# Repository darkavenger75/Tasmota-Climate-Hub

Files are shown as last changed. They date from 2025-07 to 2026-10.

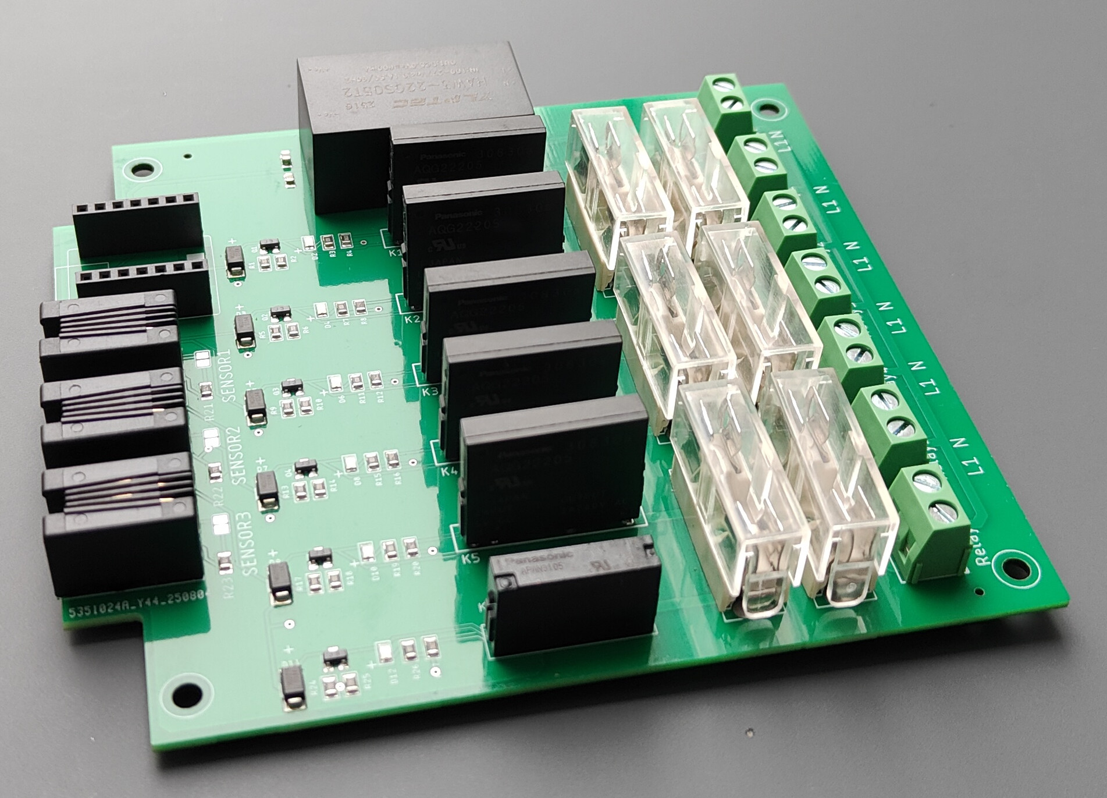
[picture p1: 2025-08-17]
NoZigbee/TasmotaTerra_PCB.jpg

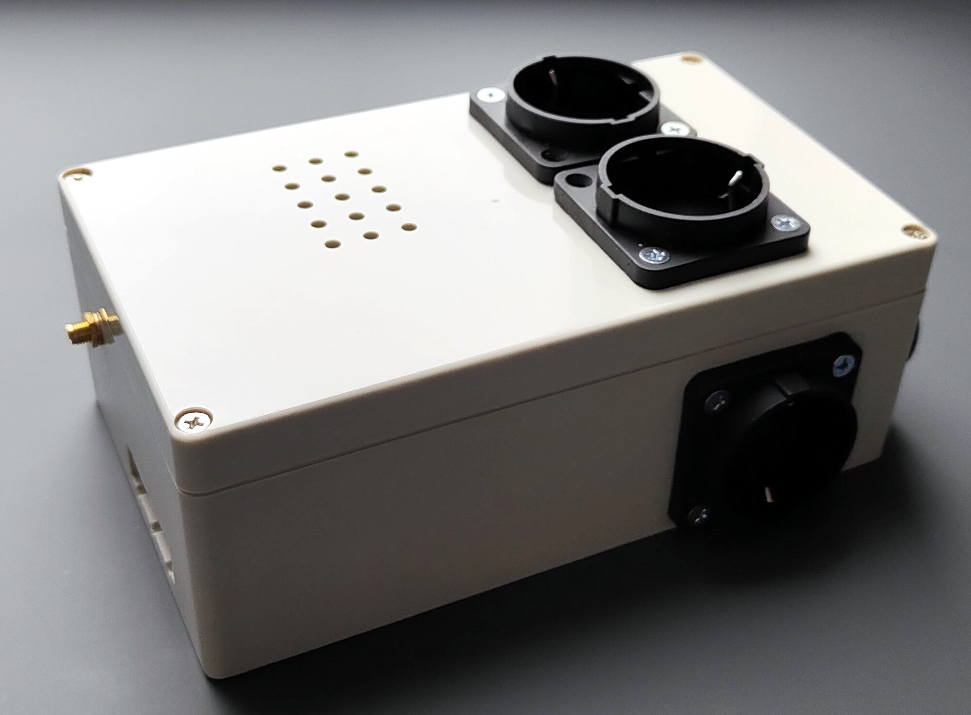
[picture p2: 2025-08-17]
NoZigbee/TasmotaTerra_Case.jpg

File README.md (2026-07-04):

Seeed Xiao ESP32-C6 based climate controller for Tasmota

A flexible Tasmota hub with 4 sensor inputs and 5 relay outputs. Can replace your collection of timer switches and thermostats (e.g. fish tank, terrarium) to allow for more complex control and the ability to check/change settings via the web interface. This is a stand-alone device not requiring internet access or any external controller/hub. Being based on Tasmota it can be integrated into e.g. Home Assistant. 
- RJ9 inputs for Sonoff WTS01 or THS01 (or whatever you want to connect requiring 1 GPIO, GND, 3.3V).
- Solid state relay main voltage outputs, max. 2A each.
- Option to add Zigbee module Ebyte E18-MS1 to integrate some of your Zigbee devices (check https://zigbee.blakadder.com/zigbee2tasmota.html for compatibility).

Instructions
- Eagle schematic, board, Gerber, BOM and CPL files are provided. Someone like JLCPCB can make the PCB and assemble it for you (check placement of components!). You might have to preorder the RJ9 sockets and solid state relays (Omron or Panasonic) or add them later yourself.
- The unit has an integrated power supply. There is mains voltage on the board, do not fry yourself!
- Flash with Tasmota for ESP32C6. If you want Zigbee support you must compile your own version, e.g. with Gitpod.
- Set-up GPIO according to "Tasmota_ESP32C6_GPIO_Config.png" and your own configuration.
- If attaching DS18x20 close the jumpers on the respective ports to add pullup resistors.
- If attaching THS01 (SI7021) add rule "ON System#Init DO DhtDelay 480,40 ENDON" or sensor might not work reliably.
- If you want the Zigbee module you have to flash it first with Z-Stack Home 1.2 coordinator firmware from https://github.com/Koenkk/Z-Stack-firmware. A debug port is provided. See https://tasmota.github.io/docs/CC2530/#flash-zigbee-adapter for options. Do not forget to close the jumper next to the board such that it will be powered.
- An example rule with 6 timers (3x ON/OFF) set to "rule" is provided. It will switch relays 1 and 2 on and off according to timers 1/2 and 3/4. It will switch relay 3 according to the temperture input from DS18B20 with limits chosen by timer 3 from mem1/mem2 (timer on) or mem3/mem4 (timer off). Unlike using the timers directly to switch the relays this rule sets the outputs correctly after restarting the device.
- I recommend to use the autoexec.be in the Berry folder instead of using rules.

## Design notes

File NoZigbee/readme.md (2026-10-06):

A different version of the Tasmota hub without Zigbee, with only 3 inputs but 6 relays, including a conventional 5A one (on GPIO23).
Can be squeezed into a Tru Components F1 TC-6649500 case together with 5 - 6 AS 45081 power sockets and a C-14 mains connector.
Or use a smaller 3D printed shell (3DShell_Tasmota_ESP32C6-6c.zip) together with Wieland GST18 i3 connectors.

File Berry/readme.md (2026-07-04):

Berry and HASPmota code to control your terrarium and show relevant data on an ESP32-4848S040 display (e.g. from https://de.aliexpress.com/item/1005007606761287.html?gatewayAdapt=glo2deu4itemAdapt). 
1) Configure the ESP32C6 climate hub as described on the main project page, including GPIO configuration.
3) Copy "autoexec.be" to the device. No other "rules" required but timers 1 (begin) and 2 (end) determine what is daytime.
4) Copy uPlot's uPlot.iife.min.js and uPlot.min.css files to the file system. This allows for creating the temperature chart without internet access.
5) Adjust timers and temperatures as desired. As a minimum timer1 and timer2 are required: day starts at timer1, ends at timer2.  
6) Install the "tasmota32s3-qio_opi" version of Tasmota on the ESP32-4848S040.
7) Use "auto-conf" and select "S3-4848S040"
8) Copy "autoexec_remote.be" - rename to "autoexec.be" - and the .jsonl file to the device.
9) Change the URL in autoexec.be to match your climate hub (currently set to http://tasmota-terra/).
10) Restart and enjoy.

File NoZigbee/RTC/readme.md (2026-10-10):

Another version:
- RTC onboard so rules depending on time will not stop working if wifi connection is lost
- Opto-isolator + TRIAC instead of SSR: cheaper given the current price of AQG2****
- Long and flat shell with Wieland connectors. Much more elegant than the Tru Components F1 TC-6649500 case

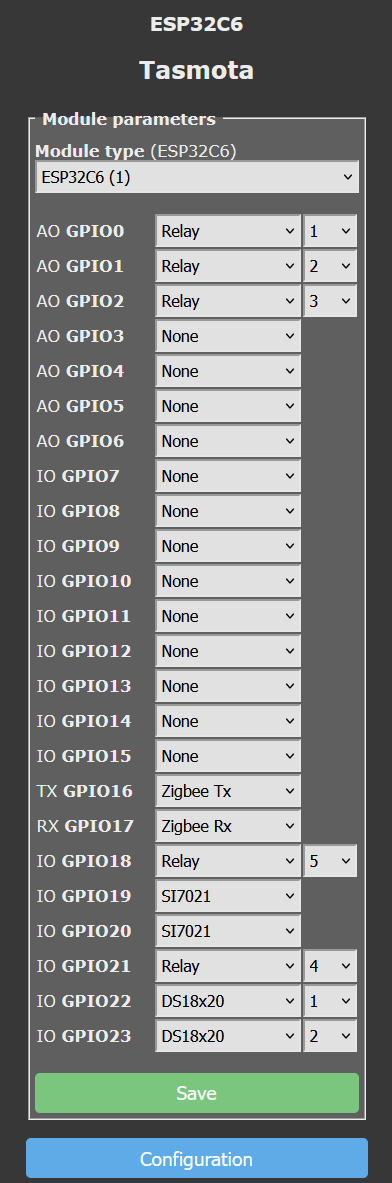
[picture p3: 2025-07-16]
Tasmota_ESP32C6_GPIO_Config.png

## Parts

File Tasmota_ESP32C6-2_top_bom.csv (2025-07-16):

Comment | Designator | Footprint | LCSC Part #
0.01uF(1KV) | C1 C2 C3 C4 C5 | C1206 | C77098
1K | R3 R7 R11 R15 R19 | R0805 | C17513
1x4P | DEBUG | 1X05 | C492404
1x7P | U$1 | XIAO_ESP32C6 | C2832270
1x7P | U$1a | XIAO_ESP32C6 | C2832270
2k | R1 R5 R9 R13 R17 | R0805 | C17604
4k7 | R21 R22 R23 R24 | R0805 | C17673
10K | R2 R6 R10 R14 R18 | R0805 | C17414
22 | R4 R8 R12 R16 R20 | R0805 | C17561
22uF | C6 | C0805 | C45783
100nF | C7 | C0805 | C49678
DB127V-5.08-2P-GN-S | X1 X2 X3 X4 X5 X6 | W237-102
FH1-206Z | F1 F2 F3 F4 F5 | FUSEHOLDER_10
GMX-N-44 | SENSOR1 SENSOR2 SENSOR3 SENSOR4 | GMX-N-4
HAW3-220S05T2 | U$3 | HAW3-220S05T2
KT-0805G | D2 D4 D6 D8 D10 | LED-0805 | C2297
S9013 | Q1 Q2 Q3 Q4 Q5 | SOT23 | C6749
SS34 | D1 D3 D5 D7 D9 | DO-214AC | C8678

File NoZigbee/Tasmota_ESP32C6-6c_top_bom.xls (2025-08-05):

Comment | Designator | Footprint | JLCPCB Part #
1K | R3,R7,R11,R15,R19,R26 | R0805 | C17513
4k7 | R21,R22,R23 | R0805 | C17673
S9013 | Q1,Q2,Q3,Q4,Q5,Q6 | SOT23 | C20069127
22uF | C6 | C0805 | C45783
2k | R1,R5,R9,R13,R17,R24 | R0805 | C17604
100nF | C7 | C0805 | C49678
APAN3105 | K6 | RELAY_APAN3105 | C90227
PTF-15 | F6,F4,F2,F5,F3,F1 | SH225 | C842712
22 | R4,R8,R12,R16,R20,R27 | R0805 | C17561
AQG22205 | K1,K2,K3,K4,K5 | AQG | C124000
GMX-N-44 | SENSOR1,SENSOR2,SENSOR3 | GMX-N-4 | C6049369
SS34 | D1,D3,D5,D7,D9,D11 | DO-214AC | C8678
1x7P | U$1,U$1B | XIAO_ESP32C6 | C2832270
10K | R2,R6,R10,R14,R18,R25 | R0805 | C17414
KT-0805G | D2,D4,D6,D8,D10,D12 | LED-0805 | C2297
DB127V-5.08-2P-GN-S | X1,X2,X3,X4,X5,X6,X7 | W237-102 | C3018698
HAW3-220S05T2 | U$3 | HAW3-220S05T2 | C19724491

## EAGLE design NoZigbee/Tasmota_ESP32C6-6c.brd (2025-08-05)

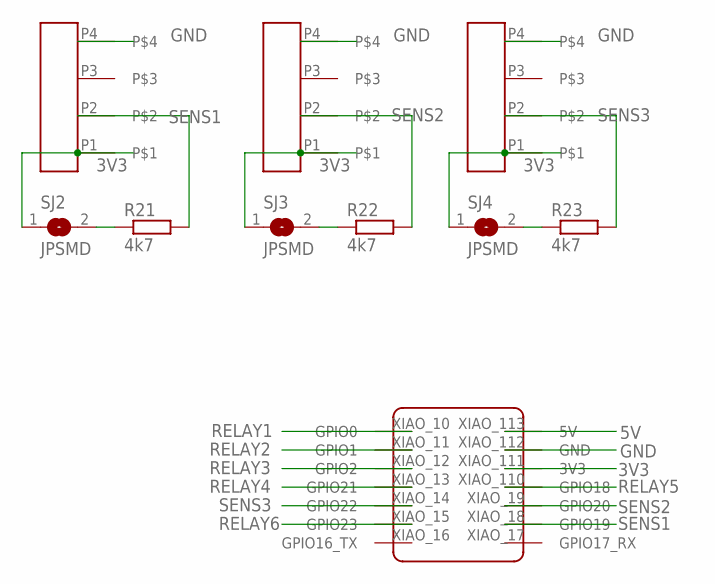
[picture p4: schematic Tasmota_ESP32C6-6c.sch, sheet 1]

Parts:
R21, R22, R23: 4k7; R0805
SENSOR1, SENSOR2, SENSOR3: GMX-N-44; GMX-N-4
SJ2, SJ3, SJ4: JPSMD; SJ
U$1: 1x7P; XIAO_ESP32C6

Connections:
3V3: SENSOR1.P1, SENSOR2.P1, SENSOR3.P1, SJ2.1, SJ3.1, SJ4.1, U$1.XIAO_111 (3V3)
5V: U$1.XIAO_113 (5V); also elsewhere on the board
GND: SENSOR1.P4, SENSOR2.P4, SENSOR3.P4, U$1.XIAO_112 (GND); also elsewhere on the board
unnamed: R21.1, SJ2.2
unnamed: R22.1, SJ3.2
unnamed: R23.1, SJ4.2
RELAY1: U$1.XIAO_10 (GPIO0); also elsewhere on the board
RELAY2: U$1.XIAO_11 (GPIO1); also elsewhere on the board
RELAY3: U$1.XIAO_12 (GPIO2); also elsewhere on the board
RELAY4: U$1.XIAO_13 (GPIO21); also elsewhere on the board
RELAY5: U$1.XIAO_110 (GPIO18); also elsewhere on the board
RELAY6: U$1.XIAO_15 (GPIO23); also elsewhere on the board
SENS1: R21.2, SENSOR1.P2, U$1.XIAO_18 (GPIO19)
SENS2: R22.2, SENSOR2.P2, U$1.XIAO_19 (GPIO20)
SENS3: R23.2, SENSOR3.P2, U$1.XIAO_14 (GPIO22)

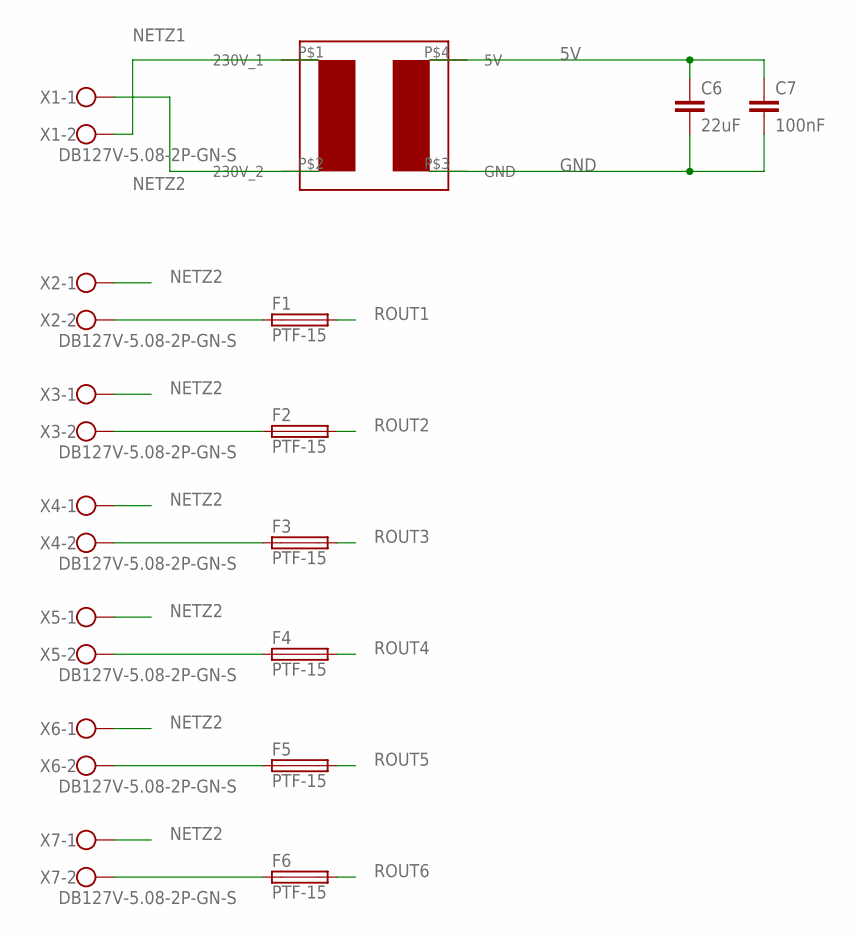
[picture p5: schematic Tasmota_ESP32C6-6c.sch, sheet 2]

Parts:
C6: 22uF; C0805
C7: 100nF; C0805
F1, F2, F3, F4, F5, F6: PTF-15; SH22,5
U$3: HAW3-220S05T2
X1, X2, X3, X4, X5, X6, X7: DB127V-5.08-2P-GN-S; W237-102

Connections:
5V: C6.1, C7.1, U$3.P$4 (5V); also elsewhere on the board
GND: C6.2, C7.2, U$3.P$3 (GND); also elsewhere on the board
unnamed: F1.1, X2.2
unnamed: F2.1, X3.2
unnamed: F3.1, X4.2
unnamed: F4.1, X5.2
unnamed: F5.1, X6.2
unnamed: F6.1, X7.2
NETZ1: U$3.P$1 (230V_1), X1.2; also elsewhere on the board
NETZ2: U$3.P$2 (230V_2), X1.1, X2.1, X3.1, X4.1, X5.1, X6.1, X7.1
ROUT1: F1.2; also elsewhere on the board
ROUT2: F2.2; also elsewhere on the board
ROUT3: F3.2; also elsewhere on the board
ROUT4: F4.2; also elsewhere on the board
ROUT5: F5.2; also elsewhere on the board
ROUT6: F6.2; also elsewhere on the board

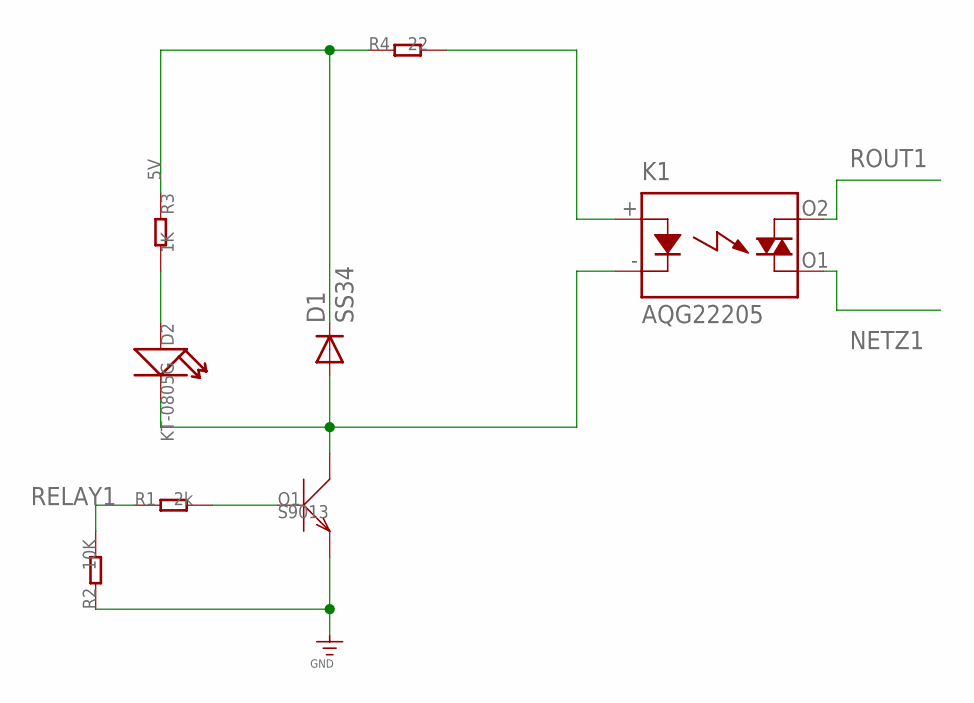
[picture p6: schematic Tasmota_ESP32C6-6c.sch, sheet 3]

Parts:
D1: SS34; DO-214AC
D2: KT-0805G; LED-0805
K1: AQG22205; AQG
Q1: S9013; SOT23
R1: 2k; R0805
R2: 10K; R0805
R3: 1K; R0805
R4: 22; R0805

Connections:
5V: D1.C, R3.1, R4.1; also elsewhere on the board
GND: Q1.2 (E), R2.1; also elsewhere on the board
unnamed: Q1.1 (B), R1.2
unnamed: D1.A, D2.-, K1.- (K), Q1.3 (C)
unnamed: D2.+, R3.2
unnamed: K1.+ (A), R4.2
NETZ1: K1.O1 (DS2); also elsewhere on the board
RELAY1: R1.1, R2.2; also elsewhere on the board
ROUT1: K1.O2 (DS1); also elsewhere on the board

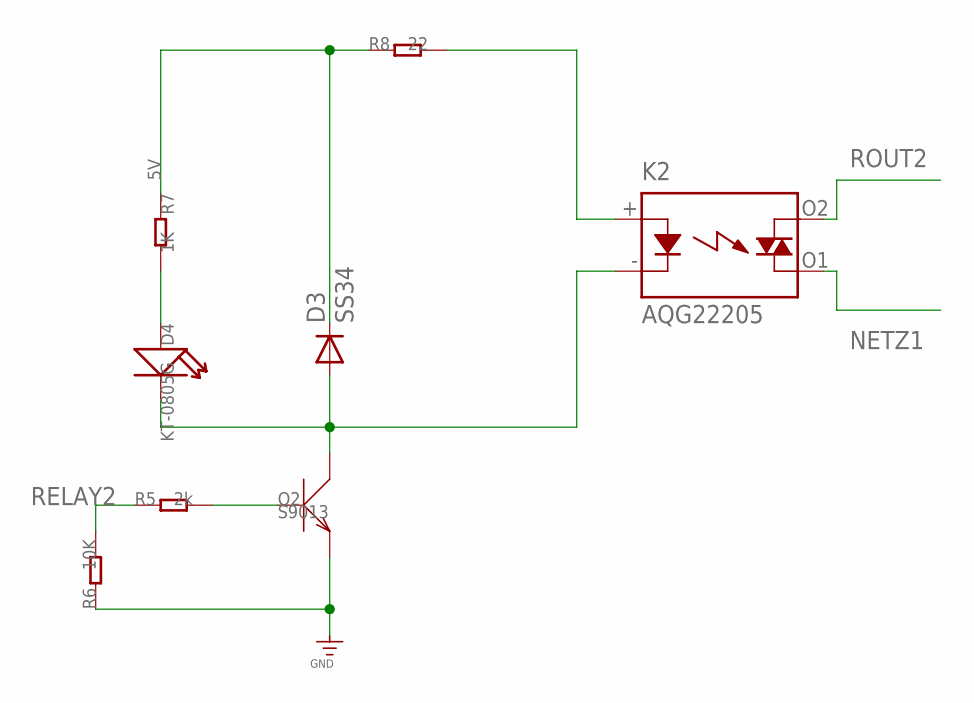
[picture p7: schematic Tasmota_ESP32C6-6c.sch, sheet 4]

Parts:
D3: SS34; DO-214AC
D4: KT-0805G; LED-0805
K2: AQG22205; AQG
Q2: S9013; SOT23
R5: 2k; R0805
R6: 10K; R0805
R7: 1K; R0805
R8: 22; R0805

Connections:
5V: D3.C, R7.1, R8.1; also elsewhere on the board
GND: Q2.2 (E), R6.1; also elsewhere on the board
unnamed: Q2.1 (B), R5.2
unnamed: D3.A, D4.-, K2.- (K), Q2.3 (C)
unnamed: D4.+, R7.2
unnamed: K2.+ (A), R8.2
NETZ1: K2.O1 (DS2); also elsewhere on the board
RELAY2: R5.1, R6.2; also elsewhere on the board
ROUT2: K2.O2 (DS1); also elsewhere on the board

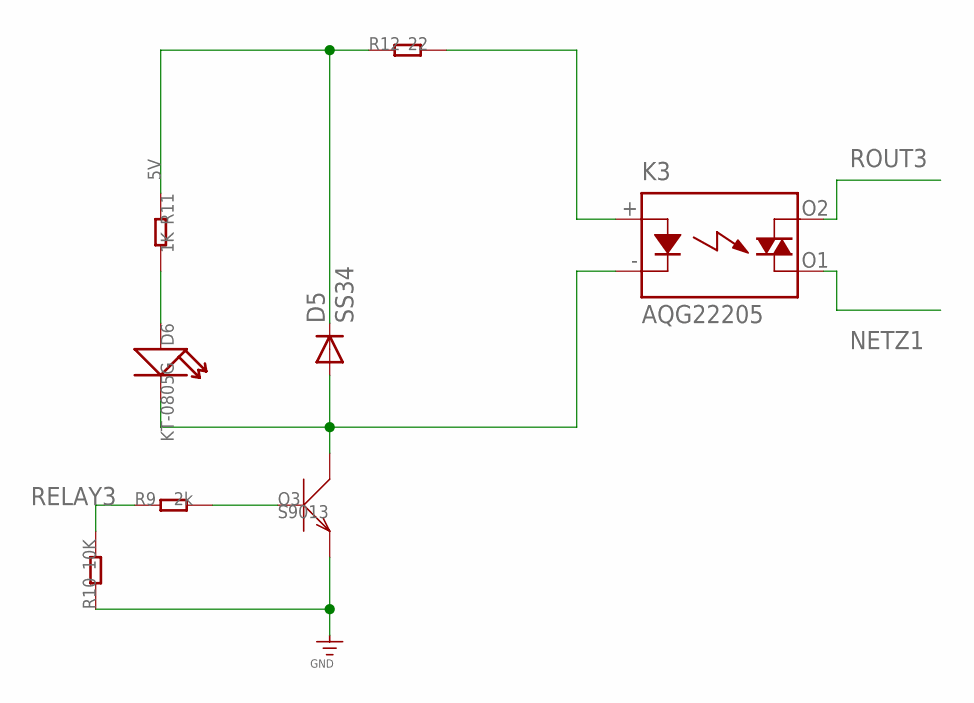
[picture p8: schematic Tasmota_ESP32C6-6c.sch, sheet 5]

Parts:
D5: SS34; DO-214AC
D6: KT-0805G; LED-0805
K3: AQG22205; AQG
Q3: S9013; SOT23
R9: 2k; R0805
R10: 10K; R0805
R11: 1K; R0805
R12: 22; R0805

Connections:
5V: D5.C, R11.1, R12.1; also elsewhere on the board
GND: Q3.2 (E), R10.1; also elsewhere on the board
unnamed: Q3.1 (B), R9.2
unnamed: D5.A, D6.-, K3.- (K), Q3.3 (C)
unnamed: D6.+, R11.2
unnamed: K3.+ (A), R12.2
NETZ1: K3.O1 (DS2); also elsewhere on the board
RELAY3: R9.1, R10.2; also elsewhere on the board
ROUT3: K3.O2 (DS1); also elsewhere on the board

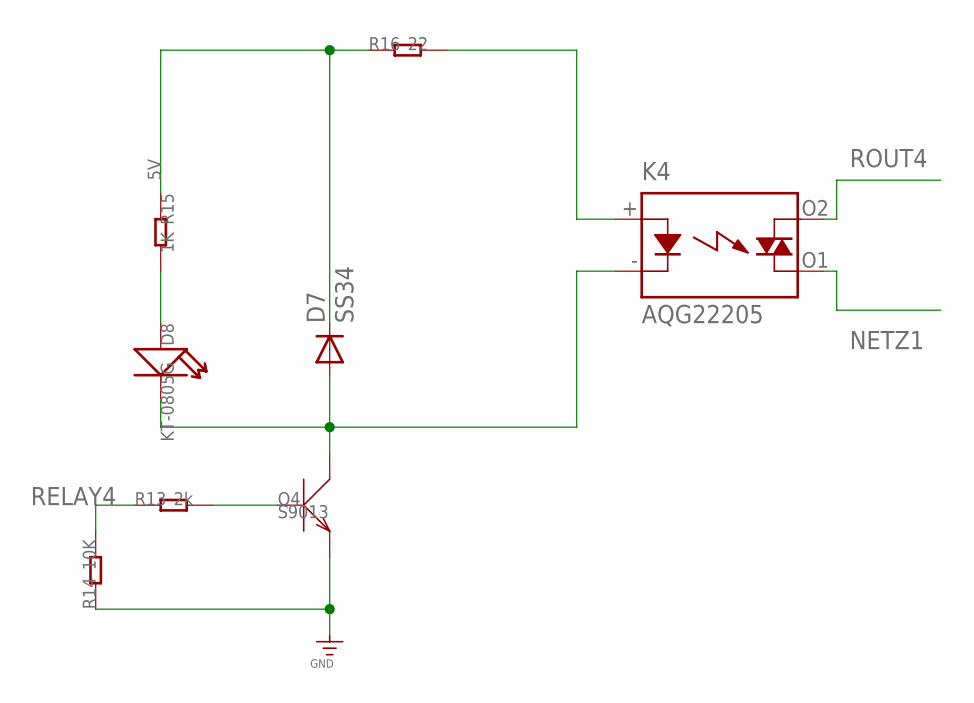
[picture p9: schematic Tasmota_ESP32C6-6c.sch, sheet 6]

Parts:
D7: SS34; DO-214AC
D8: KT-0805G; LED-0805
K4: AQG22205; AQG
Q4: S9013; SOT23
R13: 2k; R0805
R14: 10K; R0805
R15: 1K; R0805
R16: 22; R0805

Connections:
5V: D7.C, R15.1, R16.1; also elsewhere on the board
GND: Q4.2 (E), R14.1; also elsewhere on the board
unnamed: Q4.1 (B), R13.2
unnamed: D7.A, D8.-, K4.- (K), Q4.3 (C)
unnamed: D8.+, R15.2
unnamed: K4.+ (A), R16.2
NETZ1: K4.O1 (DS2); also elsewhere on the board
RELAY4: R13.1, R14.2; also elsewhere on the board
ROUT4: K4.O2 (DS1); also elsewhere on the board

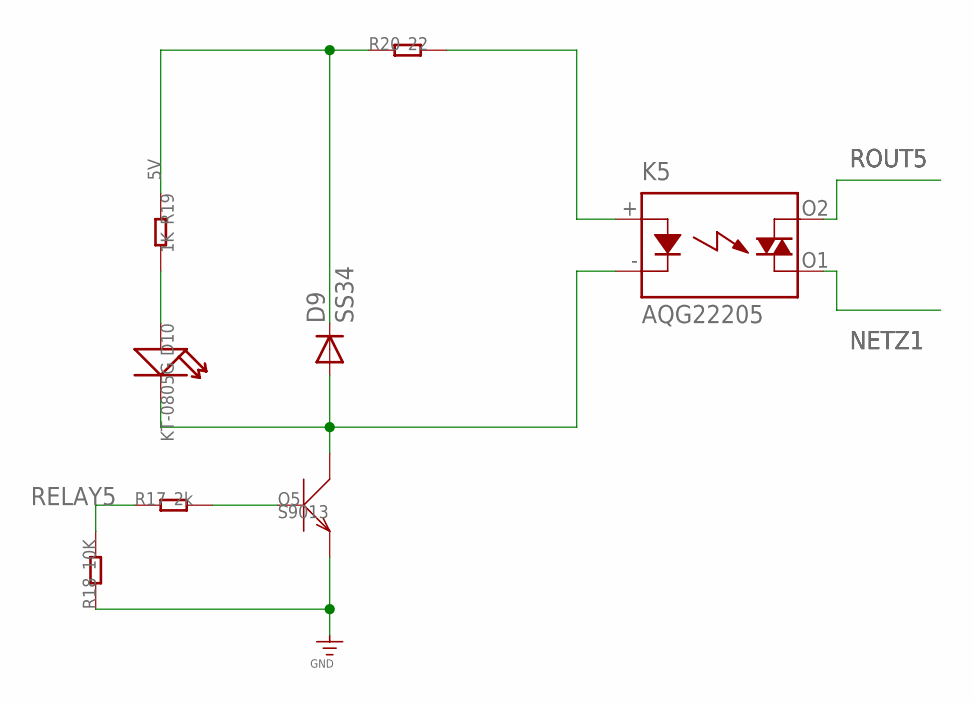
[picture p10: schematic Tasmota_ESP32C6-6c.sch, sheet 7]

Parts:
D9: SS34; DO-214AC
D10: KT-0805G; LED-0805
K5: AQG22205; AQG
Q5: S9013; SOT23
R17: 2k; R0805
R18: 10K; R0805
R19: 1K; R0805
R20: 22; R0805

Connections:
5V: D9.C, R19.1, R20.1; also elsewhere on the board
GND: Q5.2 (E), R18.1; also elsewhere on the board
unnamed: Q5.1 (B), R17.2
unnamed: D10.+, R19.2
unnamed: K5.+ (A), R20.2
unnamed: D9.A, D10.-, K5.- (K), Q5.3 (C)
NETZ1: K5.O1 (DS2); also elsewhere on the board
RELAY5: R17.1, R18.2; also elsewhere on the board
ROUT5: K5.O2 (DS1); also elsewhere on the board

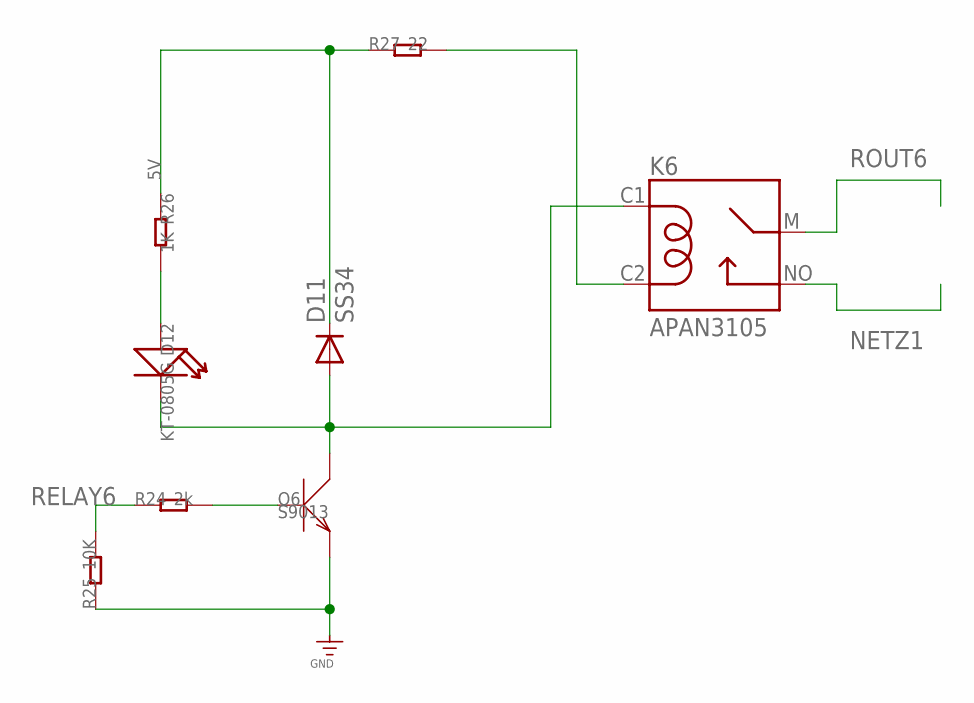
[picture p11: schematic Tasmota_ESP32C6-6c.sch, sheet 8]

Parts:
D11: SS34; DO-214AC
D12: KT-0805G; LED-0805
K6: APAN3105; RELAY_APAN3105
Q6: S9013; SOT23
R24: 2k; R0805
R25: 10K; R0805
R26: 1K; R0805
R27: 22; R0805

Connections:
5V: D11.C, R26.1, R27.1; also elsewhere on the board
GND: Q6.2 (E), R25.1; also elsewhere on the board
unnamed: Q6.1 (B), R24.2
unnamed: D11.A, D12.-, K6.C1, Q6.3 (C)
unnamed: D12.+, R26.2
unnamed: K6.C2, R27.2
NETZ1: K6.NO; also elsewhere on the board
RELAY6: R24.1, R25.2; also elsewhere on the board
ROUT6: K6.M; also elsewhere on the board

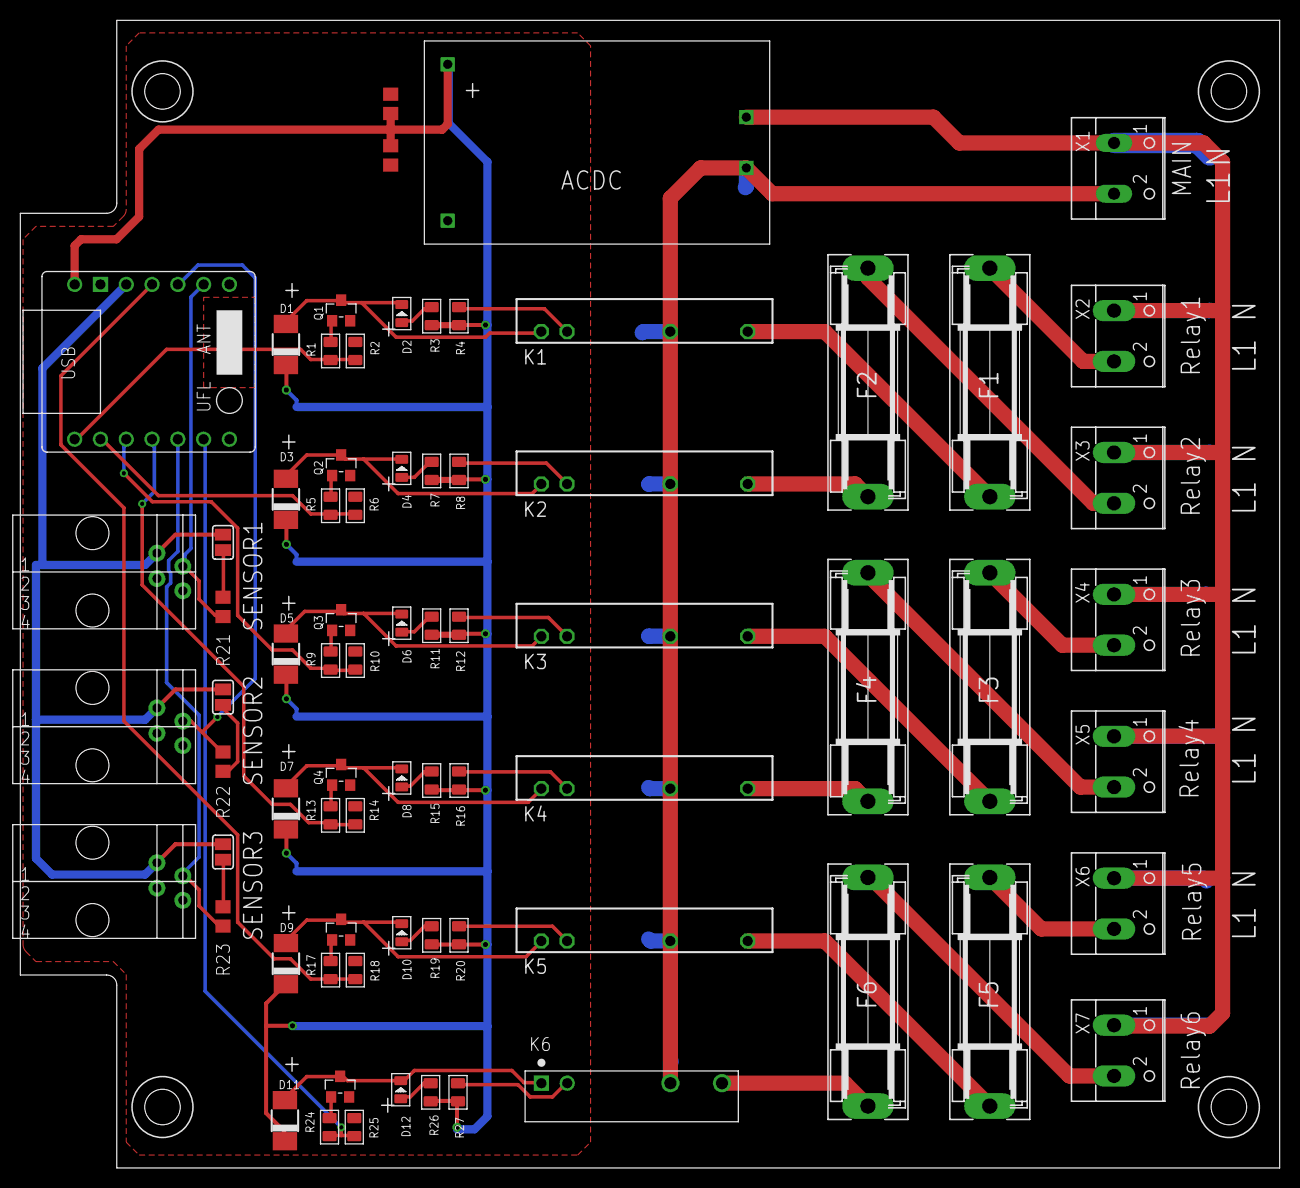
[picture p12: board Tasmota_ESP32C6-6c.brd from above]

Board: 2 copper layers, 124.0 x 113.0 mm, 74 parts (0 on the bottom side), 53 nets.
